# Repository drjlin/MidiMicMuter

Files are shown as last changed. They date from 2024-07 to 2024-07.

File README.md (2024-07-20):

# Midi Microphone Muter

This repository provides code and hardware for a little tool in the form of a Y-adapter to be used on stage to mute a single microphone by receiving a MIDI control change signal.

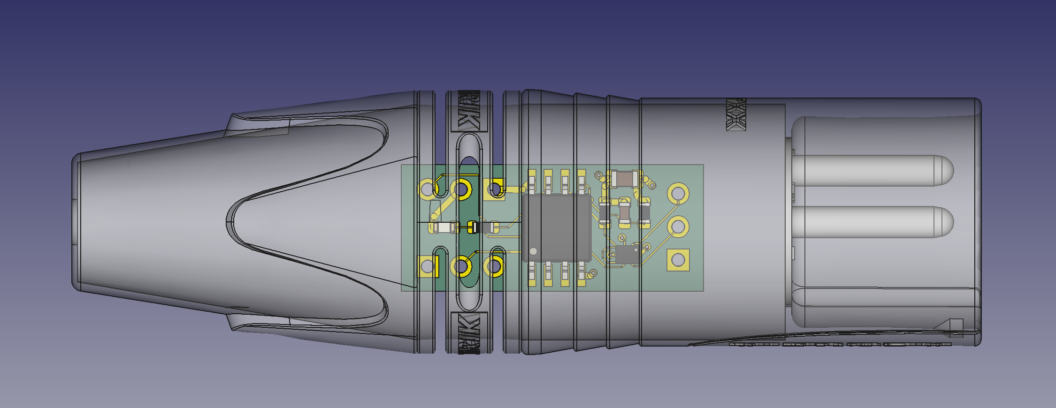
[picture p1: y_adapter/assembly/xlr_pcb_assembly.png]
assembly


## Motivation

For me as a drummer doing some additional background vocals in my band, there is always the problem of cymbal bleed on the vocal microphone signal. So while I was not singing, our live mixing engineer used to turn down the volume of my microphone signal at the risk of not having it back when needed again. Since a MIDI track was already running synchronized with our show for controlling lights and guitar effects, our mixing engineer Jakob had the idea to also use the MIDI signal to mute the microphone in those parts of the songs where it is not needed. However, all available solutions were not at all compact and satisfying, so I decided to build my own device.

## How it works

The electronics pcb is designed to fit into an XLR cable connector. This way the full device is nothing more than a Y-shaped cable with two connectors on the input side (Mic and MIDI In) and one XLR connector on the output side to deliver the occasionally muted signal to the microphone preamp.

Inspired by another blog post (https://mitxela.com/projects/midi_on_the_attiny), I decided to use the 5V power line from MIDI to power an ATtiny85 which decodes the serial MIDI data and pulls outputs high for an LED and an analog switch to turn the audio off.

Contrary to the popular advice, no optocoupler was used on the receiving unit to save space and allow to directly use MIDI as a voltage source. Pros and cons of this approach are described in detail in the link above.

Another variant of the device having the electronics mounted into a separate small box is currently in the planning phase. This would allow for proper MIDI decoupling, provide an additional MIDI Out connector and XLR connectors to make it more modular and independent of the needed cable lengths. On the downside, this would take a little more space and require another voltage source (battery, 5V connector or using microphone phantom power).

## Hardware

PCB dimensions are 23.15x9.70 mm and therefore it fits nicely into a standard XLR connector. On the input side, there are pin header terminals for MIDI In (GND, +5V, Signal) and Mic In (analog GND, Signal +, Signal -). On the output side, there is an additional Mic Out 3-pin terminal. The ATtiny85 is a cheap microcontroller which can be run without any peripherals at low power, which makes it the perfect choice for processing the program logic. TS5A22364 from Texas Instruments is a 2-channel analog switch with negative signaling capability, perfectly suited for audio switching. It takes audio Signal + and Signal - on its normally closed inputs and is connected to Mic Out on its common output pins. The only additional elements on the PCB are a 33 uF capacitor for smoothing the input voltage, a pull-up resistor and a small stabilizing 1nF capacitor on the MIDI signal line, a pull-down resistor on the output line of the ATtiny85 connecting to the analog switch and an optional LED with serial resistor to visualize when the device is in mute mode (mainly for testing).

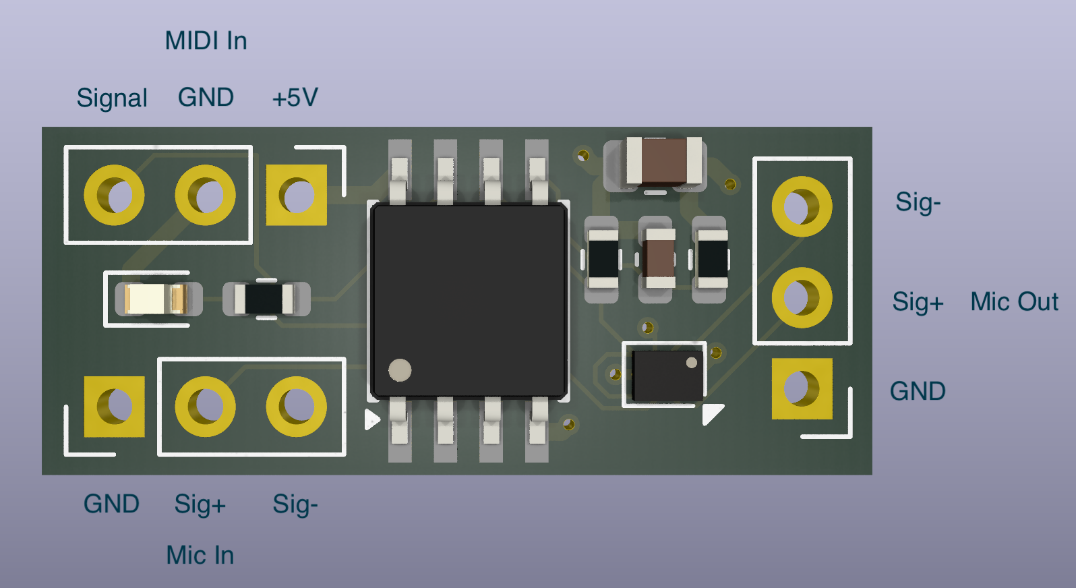
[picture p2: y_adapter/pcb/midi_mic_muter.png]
pinout


Because audio signals are connected to the normally closed pins of the analog switch, the default behavior is to let the audio flow from input to output and only mute it on respective incoming MIDI commands. But keep in mind there is no real bypass, so MIDI has to be connected (and powered) to let audio go through.

Analog (audio) GND is not connected to the digital GND by default. During tests, it was found that the two should be connected to avoid noise on the audio output, but this can easily be achieved by adding an additional cable between the respective pins.

You need to install KiCad (https://www.kicad.org) to be able to open the schematics / pcb / gerber files.

## Software

On the software side, I used a slightly modified version of Nick Gammon's MIDI decoder for ATtiny85 (https://arduino.stackexchange.com/questions/14054/interfacing-an-attiny85-with-midi-via-software-serial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). I just added the output switching logic when a control change command is received on the specified MIDI channel and CC number (by default: CC 63 on MIDI channel 7).

For programming the ATtiny85, Arduino IDE was used in combination with an Arduino nano as programmer. The procedure is described elsewhere in detail. I followed the description in this link: https://wolles-elektronikkiste.de/en/programming-attiny-with-arduino-code

You need to install Arduino IDE (https://www.arduino.cc/en/software) to be able use the included software.

## Usage

Connect microphone, MIDI in and microphone preamp. By default, the signal will be hearable. Sending CC 63 on MIDI channel 7 with a value between than 64 and 127 will mute the microphone and light up the LED. Another event with a value between 0 and 63 will unmute the line again.

## How to get it

Currently, I'm not planning to sell ready-to-use hardware. But I have some PCBs over that I don't need, so feel free to contact me if interested. Otherwise, everyone is invited to build the device on her / his own. Everything you need should be in the repository. If you have problems or questions, do not hesitate to ask.

## Feedback

Any feedback is appreciated, either on making the device more robust while maintaining the small footprint, or if there are any tips on implementing the in-a-box design. Also, please report any bugs in case you find some.

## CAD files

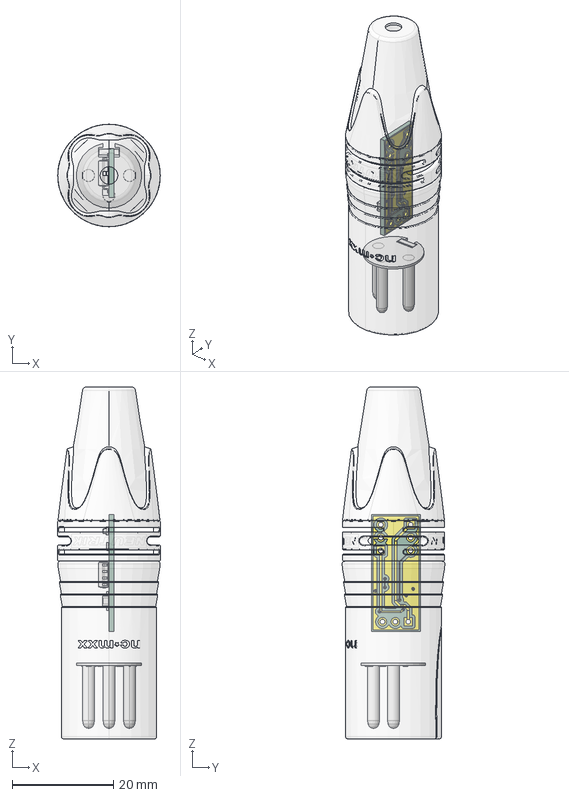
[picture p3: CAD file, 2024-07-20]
y_adapter/assembly/xlr_pcb_assembly.FCStd
20.3 x 20.3 x 69.6 mm
NC3MXX
NC3MXX001
NC3MXX002
Texas_DSBGA_10_136x186mm_Layout3x4_P05mm
R_0603_1608Metric006
R_0603_1608Metric008
LED_0603_1608Metric002
C_0603_1608Metric002
R_0603_1608Metric010
SOIC_8_5275x5275mm_P127mm
C_0805_2012Metric002
midi_mic_switch_track_1
midi_mic_switch_track_2
midi_mic_switch_track_3
midi_mic_switch_track_4
midi_mic_switch_track_5
midi_mic_switch_track_6
midi_mic_switch_track_7
midi_mic_switch_track_8
midi_mic_switch_track_9
midi_mic_switch_track_10
midi_mic_switch_track_11
midi_mic_switch_track_12
midi_mic_switch_track_13
midi_mic_switch_track_14
midi_mic_switch_track_15
midi_mic_switch_track_16
midi_mic_switch_track_17
midi_mic_switch_track_18
midi_mic_switch_track_19
midi_mic_switch_track_20
midi_mic_switch_track_21
midi_mic_switch_track_22
midi_mic_switch_track_23
midi_mic_switch_track_24
midi_mic_switch_track_25
midi_mic_switch_track_26
midi_mic_switch_track_27
midi_mic_switch_track_28
midi_mic_switch_track_29
midi_mic_switch_track_30
midi_mic_switch_track_31
midi_mic_switch_track_32
midi_mic_switch_track_33
midi_mic_switch_track_34
midi_mic_switch_track_35
midi_mic_switch_track_36
midi_mic_switch_track_37
midi_mic_switch_track_38
midi_mic_switch_track_39
midi_mic_switch_track_40
midi_mic_switch_track_41
midi_mic_switch_track_42
midi_mic_switch_track_43
midi_mic_switch_track_44
midi_mic_switch_track_45
midi_mic_switch_track_46
midi_mic_switch_track_47
midi_mic_switch_track_48
midi_mic_switch_track_49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

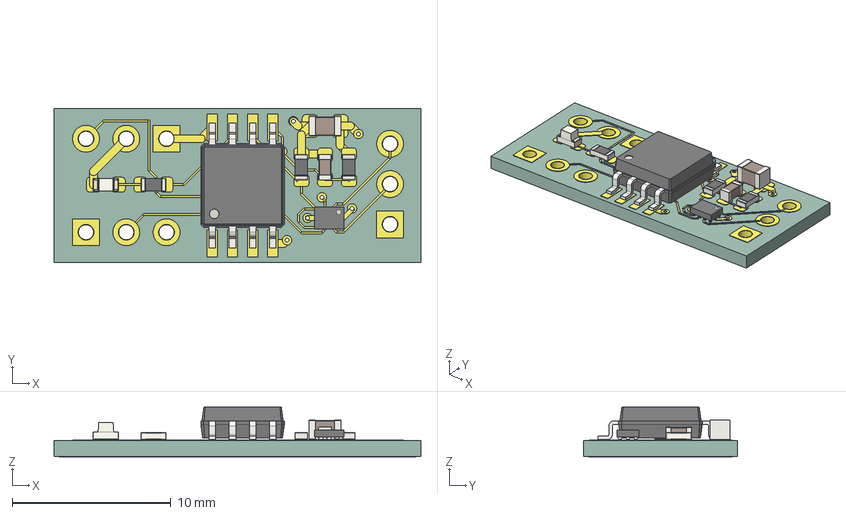
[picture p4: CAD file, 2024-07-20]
y_adapter/pcb/midi_mic_muter.step
23.1 x 9.70 x 3.14 mm
Texas_DSBGA_10_136x186mm_Layout3x4_P05mm
R_0603_1608Metric x 3
LED_0603_1608Metric
C_0603_1608Metric
SOIC_8_5275x5275mm_P127mm
C_0805_2012Metric
midi_mic_switch_track_1
midi_mic_switch_track_2
midi_mic_switch_track_3
midi_mic_switch_track_4
midi_mic_switch_track_5
midi_mic_switch_track_6
midi_mic_switch_track_7
midi_mic_switch_track_8
midi_mic_switch_track_9
midi_mic_switch_track_10
midi_mic_switch_track_11
midi_mic_switch_track_12
midi_mic_switch_track_13
midi_mic_switch_track_14
midi_mic_switch_track_15
midi_mic_switch_track_16
midi_mic_switch_track_17
midi_mic_switch_track_18
midi_mic_switch_track_19
midi_mic_switch_track_20
midi_mic_switch_track_21
midi_mic_switch_track_22
midi_mic_switch_track_23
midi_mic_switch_track_24
midi_mic_switch_track_25
midi_mic_switch_track_26
midi_mic_switch_track_27
midi_mic_switch_track_28
midi_mic_switch_track_29
midi_mic_switch_track_30
midi_mic_switch_track_31
midi_mic_switch_track_32
midi_mic_switch_track_33
midi_mic_switch_track_34
midi_mic_switch_track_35
midi_mic_switch_track_36
midi_mic_switch_track_37
midi_mic_switch_track_38
midi_mic_switch_track_39
midi_mic_switch_track_40
midi_mic_switch_track_41
midi_mic_switch_track_42
midi_mic_switch_track_43
midi_mic_switch_track_44
midi_mic_switch_track_45
midi_mic_switch_track_46
midi_mic_switch_track_47
midi_mic_switch_track_48
midi_mic_switch_track_49
midi_mic_switch_track_50
midi_mic_switch_track_51
midi_mic_switch_track_52
midi_mic_switch_track_53
midi_mic_switch_track_54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

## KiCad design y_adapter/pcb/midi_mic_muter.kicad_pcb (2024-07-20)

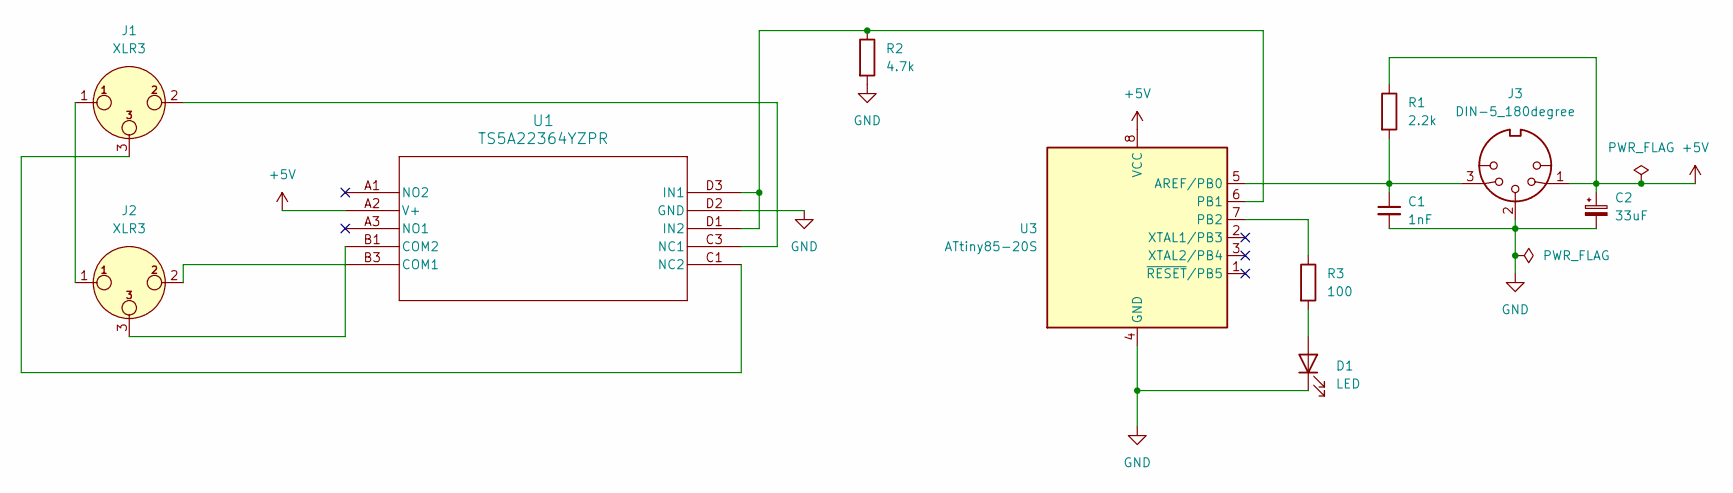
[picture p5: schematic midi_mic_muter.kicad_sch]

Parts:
C1: 1nF; C_0603_1608Metric
C2: 33uF; C_0805_2012Metric
D1: LED; LED_0603_1608Metric
J1, J2: XLR3; PinHeader_1x03_P2.54mm_Vertical
J3: DIN-5_180degree; PinHeader_1x03_P2.54mm_Vertical
R1: 2.2k; R_0603_1608Metric
R2: 4.7k; R_0603_1608Metric
R3: 100; R_0603_1608Metric
U1: TS5A22364YZPR; Texas_DSBGA-10_1.36x1.86mm_Layout3x4_P0.5mm
U3: ATtiny85-20S; SOIC-8W_5.3x5.3mm_P1.27mm

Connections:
+5V: C2.1, J3.1, R1.1, U1.A2 (V+), U3.8 (VCC)
GND: C1.2, C2.2, D1.1 (K), J3.2, R2.2, U1.D2 (GND), U3.4 (GND)
unnamed: D1.2 (A), R3.2
unnamed: J1.1, J2.1
unnamed: J2.2, U1.B3 (COM1)
unnamed: J2.3, U1.B1 (COM2)
unnamed: R2.1, U1.D1 (IN2), U1.D3 (IN1), U3.6 (PB1)
unnamed: J1.2, U1.C3 (NC1)
unnamed: J1.3, U1.C1 (NC2)
unnamed: C1.1, J3.3, R1.2, U3.5 (AREF/PB0)
unnamed: R3.1, U3.7 (PB2)

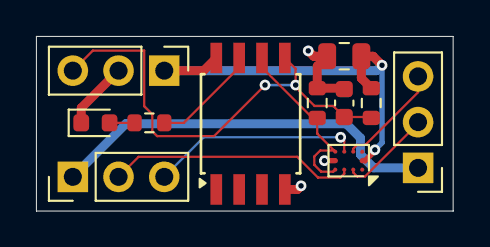
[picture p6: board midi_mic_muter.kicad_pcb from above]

Board: 2 copper layers, 23.1 x 9.7 mm, 11 parts (0 on the bottom side), 11 nets.

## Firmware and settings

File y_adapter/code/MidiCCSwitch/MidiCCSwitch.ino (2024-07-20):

// MIDI_decoder for ATtiny85
//
// This code is a modification of Nick Gammons Midi decoder for ATtiny85, as described and released here:
// https://arduino.stackexchange.com/questions/14054/interfacing-an-attiny85-with-midi-via-software-serial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
//
// Original Version fpr Arduino Uno (ny Nick Gammon): http://www.gammon.com.au/forum/?id=12746
//
// Descrption:
// The decoder listens to control change MUTE_CC on Midi channel MUTE_CHANNEL and switches an LED and an analog switch connected to pins 7 and 6, respectively.
// Received values between 0 and 63 put both pins LOW and values between 64 and 127 put the two pins HIGH.
//  
// ATMEL ATTINY 25/45/85 / ARDUINO
// Pin 1 is /RESET
//
//                  +-\/-+
// Ain0 (D 5) PB5  1|    |8  Vcc
// Ain3 (D 3) PB3  2|    |7  PB2 (D 2) Ain1 
// Ain2 (D 4) PB4  3|    |6  PB1 (D 1) pwm1
//            GND  4|    |5  PB0 (D 0) pwm0
//                  +----+


#include <SoftwareSerial.h>

const byte LED = 2;   // pin 7 on ATtiny85
const byte SWITCH = 1;  // pin 6

// Plug MIDI into pin D2 (MIDI in serial) (pin 7 on ATtiny85)

SoftwareSerial midi (0, 4);  // Rx, Tx

// Channel and CC to listen to
const byte MUTE_CHANNEL = 7;
const byte MUTE_CC = 63;

const int noRunningStatus = -1;

int runningStatus;
unsigned long lastRead;
byte lastCommand;

void setup() {
  //  Set MIDI baud rate:
  midi.begin(31250);
  runningStatus = noRunningStatus;
  pinMode (LED, OUTPUT);
} // end of setup

void RealTimeMessage (const byte msg)
  {
    // ignore realtime messages
  } // end of RealTimeMessage

// get next byte from serial (blocks)
int getNext ()
  {

  if (runningStatus != noRunningStatus)
    {
    int c = runningStatus;
    // finished with look ahead
    runningStatus = noRunningStatus;
    return c;
    }

  while (true)
    {
    while (midi.available () == 0)
      {}
    byte c = midi.read ();
    if (c >= 0xF8)  // RealTime messages
      RealTimeMessage (c);
    else
      return c;
    }
  } // end of getNext

const char * notes [] = { "C ", "C#", "D ", "D#", "E ", "F ", "F#", "G ", "G#", "A ", "A#", "B " };

byte note;
byte octave;
byte velocity;
byte cc_message;
byte cc_param;

// interpret a note in terms of note name and octave
void getNote ()
  {
  note = getNext ();
  octave = note / 12;
  note %= 12;
  }  // end of getNote

void getVelocity ()
  {
  velocity = getNext ();
  }

// show a control message 
void showControlMessage ()
  {
  cc_message =  getNext () & 0x7F;
  cc_param = getNext ();
  }  // end of showControlMessage

// read a system exclusive message 
void showSystemExclusive ()
  {
  int count = 0;
  while (true)
    {
    while (midi.available () == 0)
      {}
    byte c = midi.read ();
    if (c >= 0x80)
      {
      runningStatus = c;
      return;  
      }

    } // end of reading until all system exclusive done
  }  // end of showSystemExclusive

void loop() 
{
  byte c = getNext ();
  unsigned int parameter;

  if (((c & 0x80) == 0) && (lastCommand & 0x80))
    {
    runningStatus = c;
    c = lastCommand; 
    }

  // channel is in low order bits
  int channel = (c & 0x0F) + 1;

  // messages start with high-order bit set
  if (c & 0x80)
    {
    lastCommand = c;
    switch ((c >> 4) & 0x07)
      {
      case 0:   // Note off
        getNote ();
        getVelocity ();
        // only for testing with piano - comment in production
        digitalWrite (LED, LOW);
        digitalWrite (SWITCH, LOW);
        // end
        break;

      case 1:   // Note on
        getNote ();
        getVelocity ();
        // only for testing with piano - comment in production
        if (velocity == 0) {
          digitalWrite (LED, LOW);
          digitalWrite (SWITCH, LOW);
        }
        else
          if ((channel == 1) && (note == 0) && (octave == 3)) {
            digitalWrite (LED, HIGH);
            digitalWrite (SWITCH, HIGH);
          }
        // end
        break;

      case 2:  // Polyphonic pressure
        getNote ();
        parameter = getNext ();  // pressure
        break;

      case 3: // Control change
        showControlMessage ();
        if ((channel == MUTE_CHANNEL) && (cc_message == MUTE_CC) && (cc_param < 64)) {
          digitalWrite (LED, LOW);
          digitalWrite (SWITCH, LOW);
        }
        else if ((channel == MUTE_CHANNEL) && (cc_message == MUTE_CC) && (cc_param >= 64)) {
          digitalWrite (LED, HIGH);
          digitalWrite (SWITCH, HIGH);
        }
        break;

      case 4:  // Program change
        parameter = getNext ();  // program
        break;

      case 5: // After-touch pressure
        parameter = getNext (); // value
        break;

      case 6: // Pitch wheel change 
        parameter = getNext () |  getNext () << 7; 
        break;

      case 7:  // system message
        {
        lastCommand = 0;           // these won't repeat I don't think
        switch (c & 0x0F)
          {
          case 0: // Exclusive
            parameter = getNext (); // vendor ID
            showSystemExclusive ();
            break;

          case 1: // Time code
            parameter = getNext () ;
            break;

          case 2:  // Song position 
            parameter = getNext () |  getNext () << 7; 
            break;

          case 3: // Song select
            parameter = getNext () ;  // song
            break;

          case 4:    // reserved
          case 5:    // reserved
          case 6:    // tune request
          case 7:    // end of exclusive
          case 8:    // timing clock
          case 9:    // reserved
          case 10:   // start
          case 11:   // continue
          case 12:   // stop
          case 13:   // reserved
          case 14:   // active sensing
          case 15:   // reset
             break;

          }  // end of switch on system message  

        }  // end system message
        break;
      }  // end of switch
    }  // end of if
  else
    {
    // unexpected, ignore 
    }

}  // end of loop
